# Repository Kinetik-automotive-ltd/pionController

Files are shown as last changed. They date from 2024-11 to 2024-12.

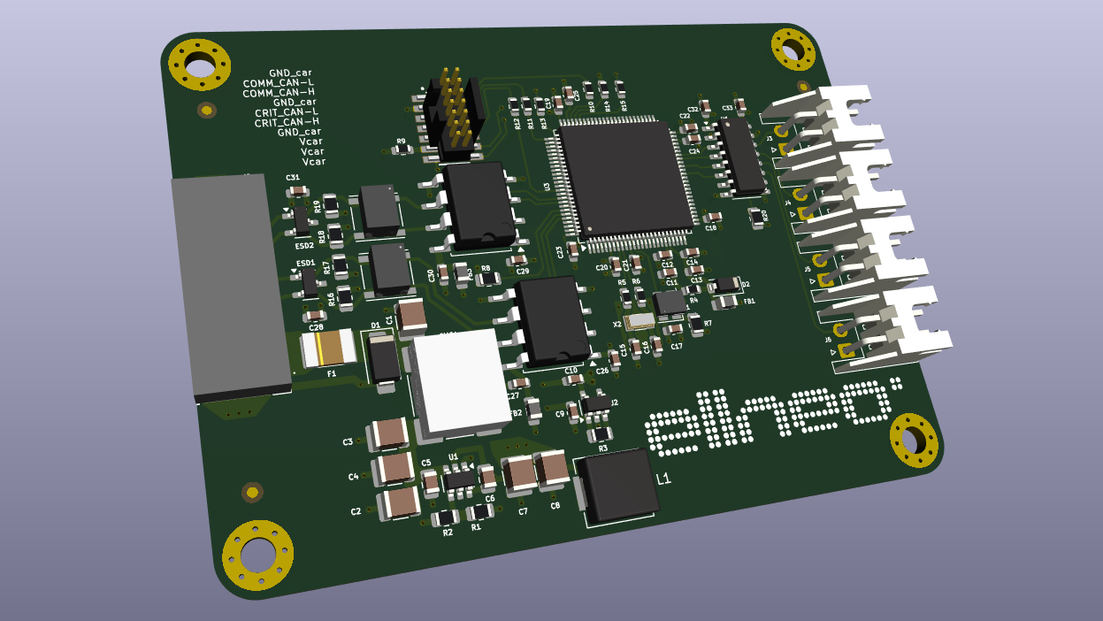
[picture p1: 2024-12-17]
Fabrication files/Additional files/Front_View.png

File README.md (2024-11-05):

# PionController
Repo for STM32 based PION rearlight controller

Top view

Bottom view

**Overview**

The Pion backlight control board is engineered to manage a 7x109 pixel LED matrix backlight within automotive interiors. This board leverages the STM32H743VITx microcontroller for LED control, offering dynamic picture displaying.

### Key Components

-   **Main Processor**: The STM32H743VITx microcontroller drives the control and processing of the LED matrix.
-   **CAN Transceivers**:
    -   **CAN Common**: Handles standard communication for routine vehicle operations.
    -   **CAN Critical**: Dedicated line for critical or high-priority messages within the system.
-   **Power Regulation**:
    -   **12V to 5V Regulator**: Provides a 5V supply.
    -   **5V to 3.3V Regulator**: Additional power regulation for the STM32.
-   **ESD Protection Circuit**: Protects sensitive components from electrostatic discharge.
-   **GPIO Pins (4)**: Converted from 3.3V to 5V via a voltage regulator, ensuring compatibility with external systems operating at higher voltages.

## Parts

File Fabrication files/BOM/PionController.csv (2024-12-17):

Id | Designator | Footprint | Quantity | Designation | Supplier and ref
1 | L1 | L_Sunlord_MWSA0603S | 1 | 3.3uH
2 | C13,C10,C25,C9,C11,C24,C17 | C_0603_1608Metric | 7 | 2.2uF
3 | C5,C6 | C_0805_2012Metric | 2 | 100nF
4 | U2 | SOT-23-5 | 1 | TLV75733PDBV
5 | R9,R10,R12,R13,R11 | R_0603_1608Metric | 5 | 100
6 | D1 | D_SMA | 1 | SMAJ18A
7 | C29,C23,C20,C32,C21,C12,C19,C26,C33,C30,C27,C31,C18,C22,C28,C14 | C_0603_1608Metric | 16 | 100nF
8 | CMC2,CMC3 | L_CommonModeChoke_Murata_DLW5BTMxxxSQ2x_5x5mm | 2 | DLW43SH101XK2L
9 | U5,U4 | SOP-8_6.62x9.15mm_P2.54mm | 2 | ISO1050DUB
10 | C3,C1,C8,C2,C4,C7 | C_1210_3225Metric | 6 | 10uF
11 | FB3,FB2,FB1 | L_0805_2012Metric | 3 | 200R/100MHz 500mA
12 | J2 | SM10B-ULHK-1TA1-ETB_HF | 1 | SM10B-ULHK-1TA1-ETB_HF_
13 | R6,R14,R5,R15 | R_0603_1608Metric | 4 | 0
14 | R8,R7,R3,R20,R2 | R_0805_2012Metric | 5 | 10K
15 | U1 | SOT-23-6 | 1 | TPS562200
16 | R19,R18,R16,R17 | R_0805_2012Metric | 4 | 60.4
17 | R4 | R_0603_1608Metric | 1 | 47
18 | J5,J3,J6,J4 | JST_XH_S2B-XH-A_1x02_P2.50mm_Horizontal | 4 | Conn_01x02
19 | X1 | Oscillator_SMD_Abracon_ASE-4Pin_3.2x2.5mm | 1 | ASE-16.00MHz
20 | D2 | D_SOD-123 | 1 | 1N5819W1
21 | U3 | LQFP-100_14x14mm_P0.5mm | 1 | STM32H743VITx
22 | U6 | SOIC-16_3.9x9.9mm_P1.27mm | 1 | CA-IS3740HN
23 | F1 | Fuse_1812_4532Metric | 1 | 2.6A PPTC
24 | C15,C16 | C_0603_1608Metric | 2 | 22pF
25 | R1 | R_0805_2012Metric | 1 | 54.9K
26 | J1 | SAMTEC_FTSH-107-01-L-DV-K-A | 1 | FTSH-107-01-L-DV-K-A
27 | ESD1,ESD2 | SOT-23-3 | 2 | CDSOT23-SM712
28 | X2 | Crystal_SMD_3215-2Pin_3.2x1.5mm | 1 | 32.768kHZ
29 | CMC1 | L_CommonModeChoke_Wuerth_WE-SL5 | 1 | PSMCAQ1050-801P

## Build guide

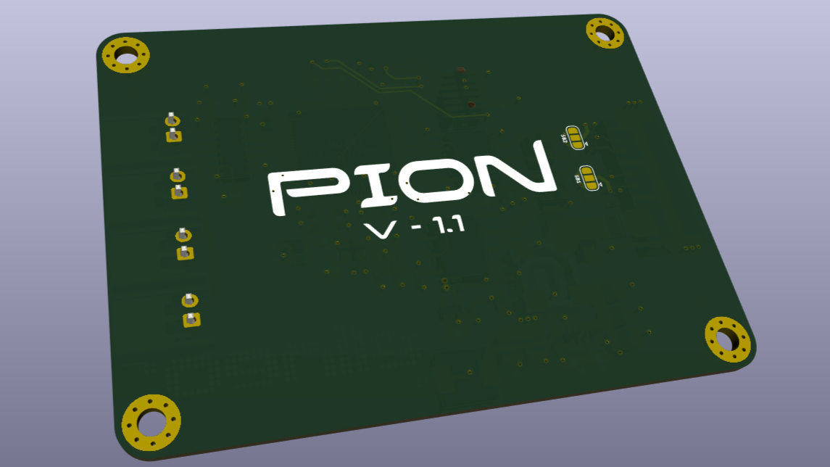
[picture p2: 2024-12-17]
Fabrication files/Additional files/Back_View.png

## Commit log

2024-10-17 just messing aroung
    [PionController.kicad_pcb]
2024-10-17 commit to be happy
    [CAN.kicad_sch, PionController.kicad_pcb, connectors.kicad_sch]
2024-10-19 Version 1
    [PionController.kicad_pcb, connectors.kicad_sch, untitled.kicad_sch]
2024-10-19 Version 1.2
    [PionController.kicad_pcb]
2024-10-19 Version 1.3 the gpio lines are thinner making the board a little shorter
    [PionController.kicad_pcb]
2024-10-19 version 1.3, fixing small error
    [PionController.kicad_pcb]
2024-10-19 adding board outline
    [PionController.kicad_pcb, PionController.kicad_sch]
2024-10-22 fixed Crystal osc and added a 5V and a 3.3V power plane
    Added 5V and 3.3V power plane, fixed crystal oscylator, reordered some components
    [PionController.kicad_pcb]
2024-10-23 Can reorder
    [PionController.kicad_pcb]
2024-10-23 Fixing issues with decoupling capacitors and addressing other minor adjustments.
    [PionController.kicad_pcb]
2024-10-23 Fixing one forgotten decoupling capacitor.
    [PionController.kicad_pcb]
2024-10-23 Power plane update
    [PionController.kicad_pcb]
2024-10-23 Ground plane fix
    [PionController.kicad_pcb]
2024-10-23 Before Library Fix (in case it goes wrong)
    [PionController.kicad_pcb]
2024-10-23 Librery fix, 3d models added and fiducial marks
    Library Fix: Added missing components and updated footprints, ensuring all parts are properly referenced.
    3D Models Added: Integrated 3D models for visual reference in the PCB layout and to assist with mechanical fitment checks.
    Fiducial Marks: Placed fiducial marks on the board for accurate alignment during automated assembly processes.
    [CAN.kicad_sch, PionController.kicad_pcb, connectors.kicad_sch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]
2024-10-24 Fixed mispositioned elements, made power and ground connections thicker, and cleared the power plane gap from vias.
    [PionController.kicad_pcb]
2024-10-24 fixing logo scale
    [PionController.kicad_pcb]
2024-10-25 Added the last 3D model
    [PionController.kicad_pcb]
2024-10-29 Fixing Ivan's remarks and adding the forgotten pull-down resistor
    [CAN.kicad_sch, PionController.kicad_pcb, PionController.kicad_sch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]
2024-10-29 Added a ground plane beneath the input connector
    [PionController.kicad_pcb]
2024-10-29 Fixing based on H3lgi's recommendations
    [PionController.kicad_pcb]
2024-10-29 Fixed reference designators in SCH and moved PCB silkscreen positions for better visibility
    [CAN.kicad_sch, PionController.kicad_pcb, PionController.kicad_sch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]
2024-11-04 Added the fabrication files and updated the readme
    [PionController-B_Cu.gbr, PionController-B_Mask.gbr, PionController-B_Paste.gbr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]
2024-11-05 Fixing fabrication files
    [PionController-B_Cu.gbr, PionController-B_Mask.gbr, PionController-B_Paste.gbr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]
2024-12-17 New version 1.1
    Fixing the inductor, the mixed up CPU the resistors, and the f.silkscreen and b.silkscreen.
    [CAN.kicad_sch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]
